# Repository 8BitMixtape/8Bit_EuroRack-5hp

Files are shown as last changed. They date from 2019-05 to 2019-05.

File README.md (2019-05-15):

# 8Bit_EuroRack-5hp

This was the first design and concept... 

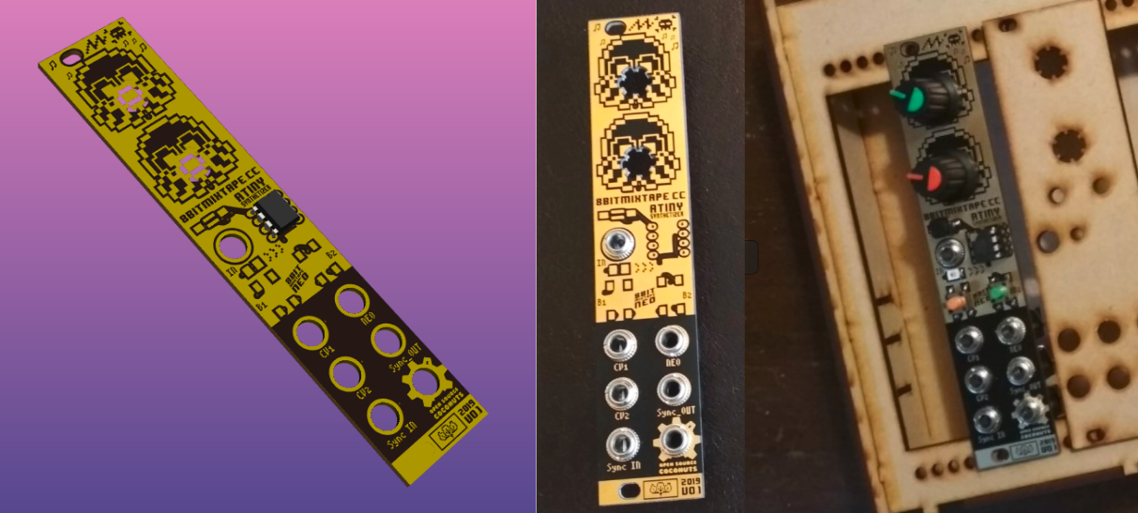
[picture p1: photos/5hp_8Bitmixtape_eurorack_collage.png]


* single PCB layer as frontplate AND circuit
* screw pots with solded pads on backside, like the 8Bit Mixtape NEO
* Vertical 3.5mm jacks, needs a bit of wiring to the PCB
* Attiny85 Chip on frontside. 8bit style

## Connections
* IN (for programming with audio)
* CV1 and CV2 IN - Connected to the input of potentiometers
* Sync IN - same connection as buttons. read as High to check for Sync signal (still needs to be coded)
* Sync OUT - from reset pin aka PB5 - change fuse settings to disable reset and solder little jumperpads on PCB
* NEO OUT - from PB0 to control NEO-Pixels or use as any other I/O pin.
* Coconut - That's the Main sound output aka PB0 with little RC filter

## Interface design drafts

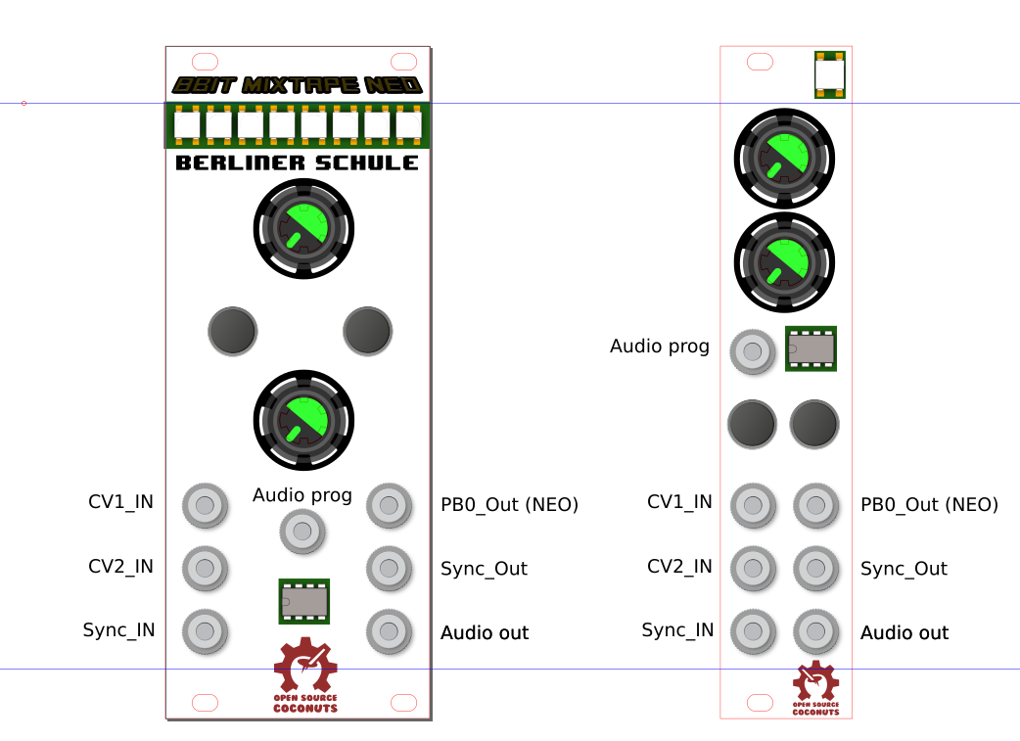
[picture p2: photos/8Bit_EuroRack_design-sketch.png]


## KiCAD PCB and 3d View

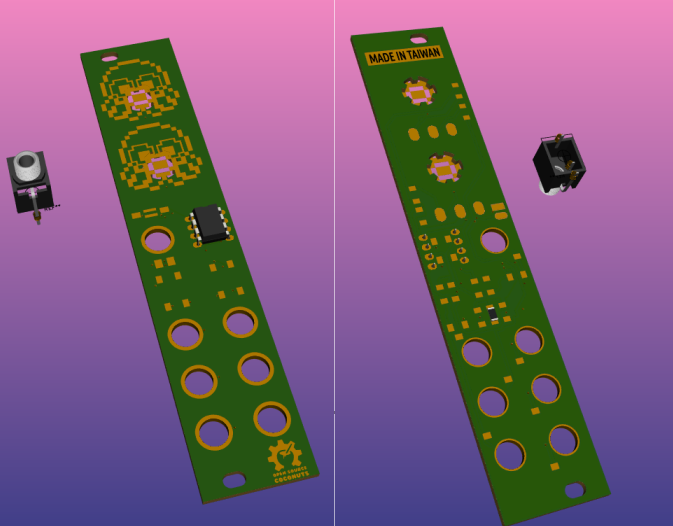
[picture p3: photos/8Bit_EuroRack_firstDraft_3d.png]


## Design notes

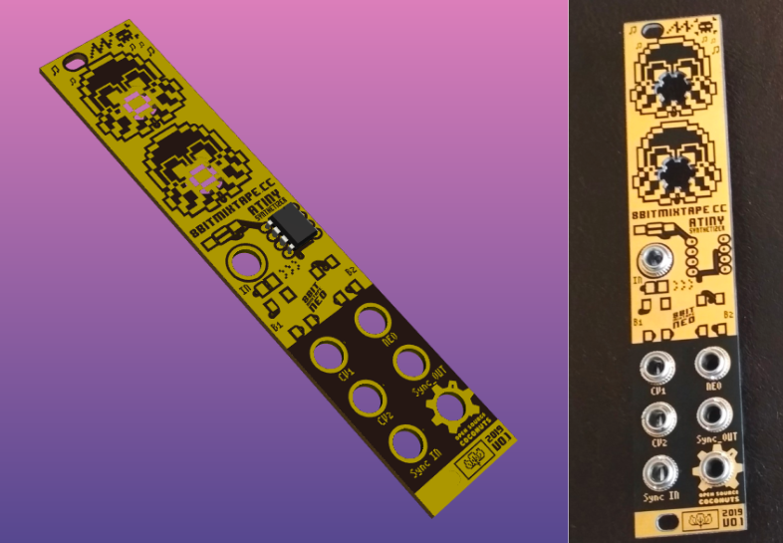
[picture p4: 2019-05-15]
photos/5hp_8Bitmixtape_eurorack.png

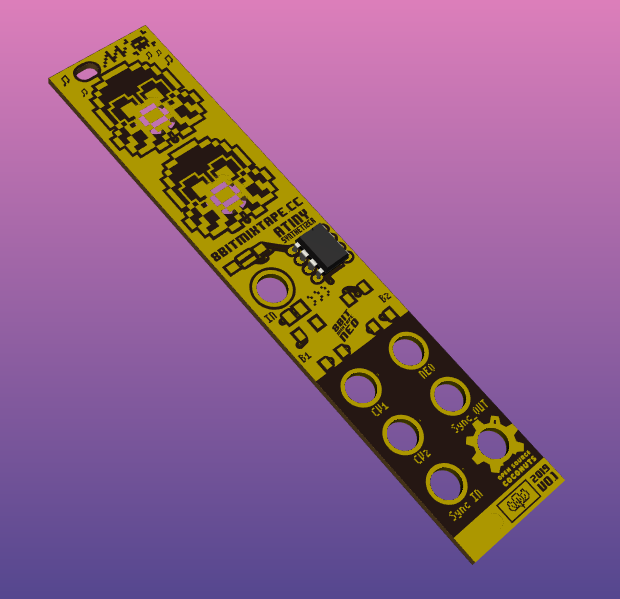
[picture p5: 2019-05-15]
photos/8Bit_EuroRack_v01_3d.png

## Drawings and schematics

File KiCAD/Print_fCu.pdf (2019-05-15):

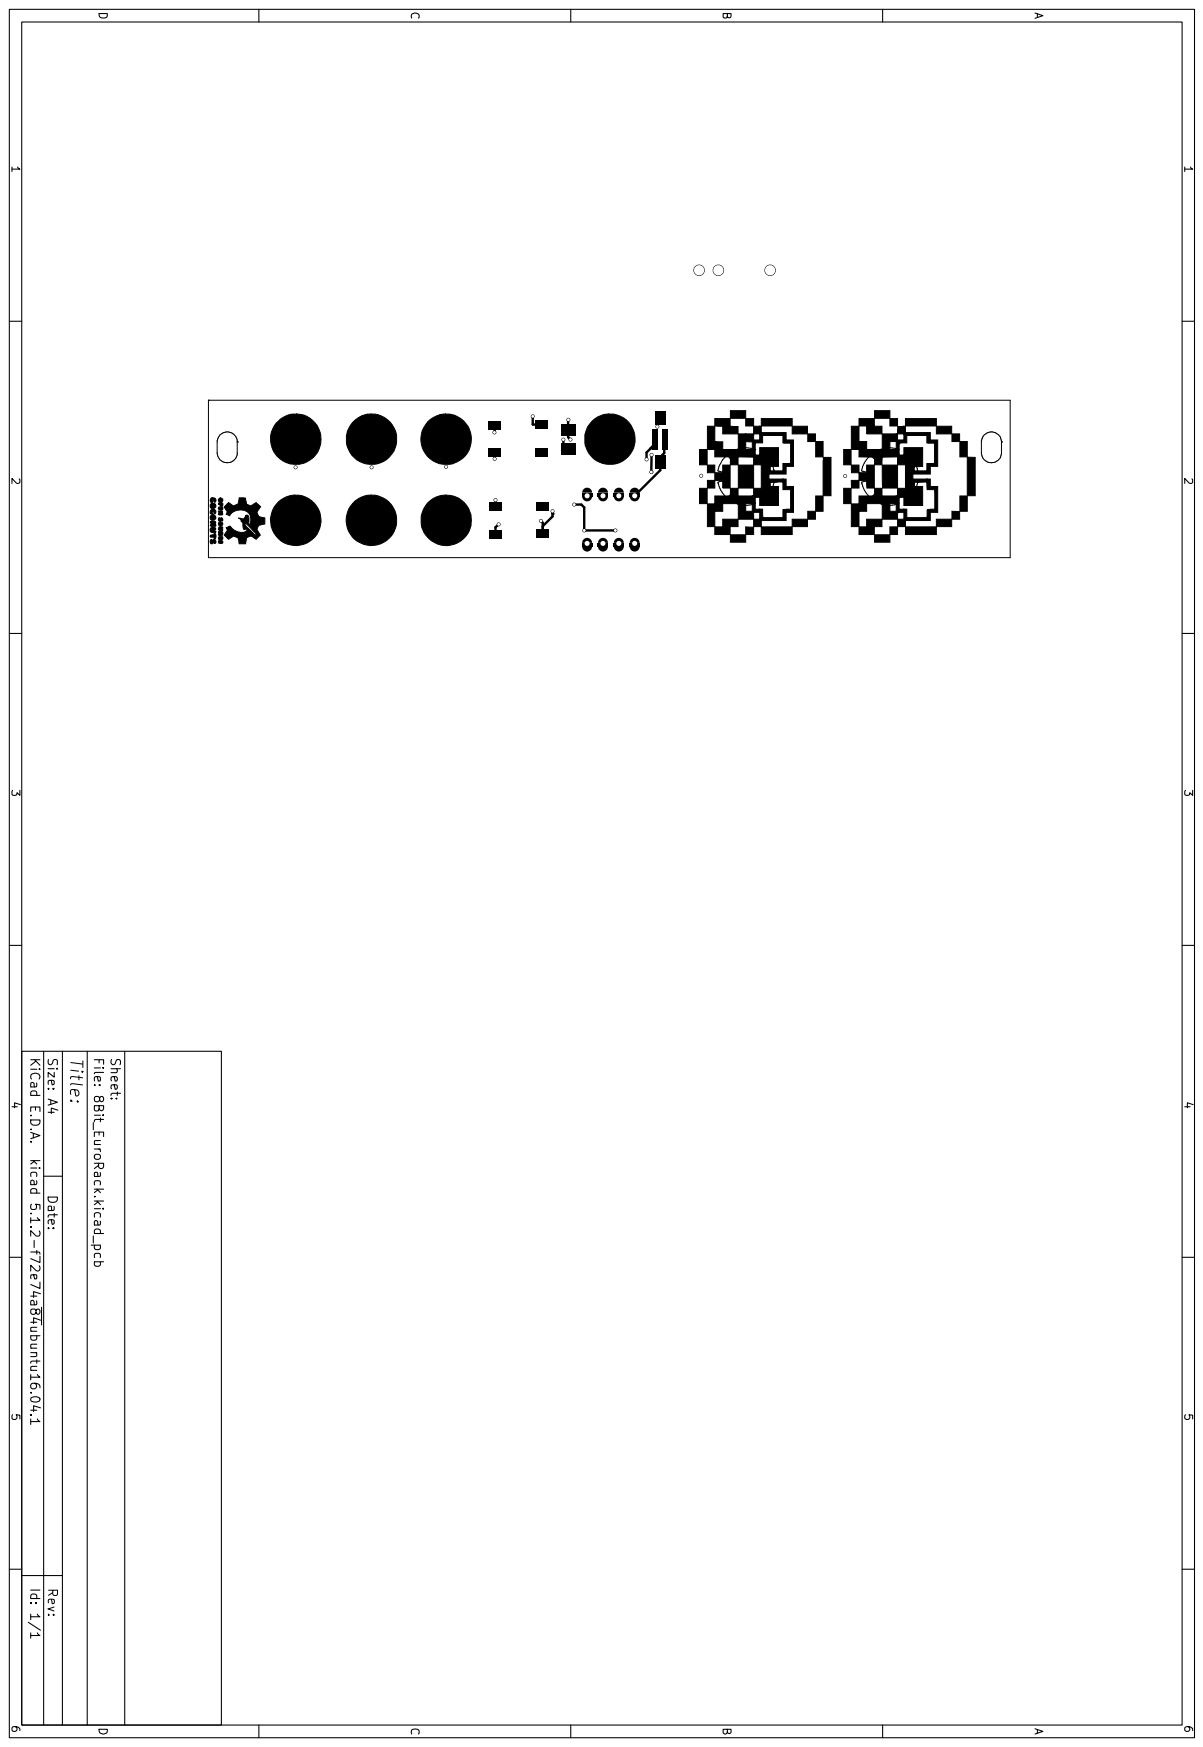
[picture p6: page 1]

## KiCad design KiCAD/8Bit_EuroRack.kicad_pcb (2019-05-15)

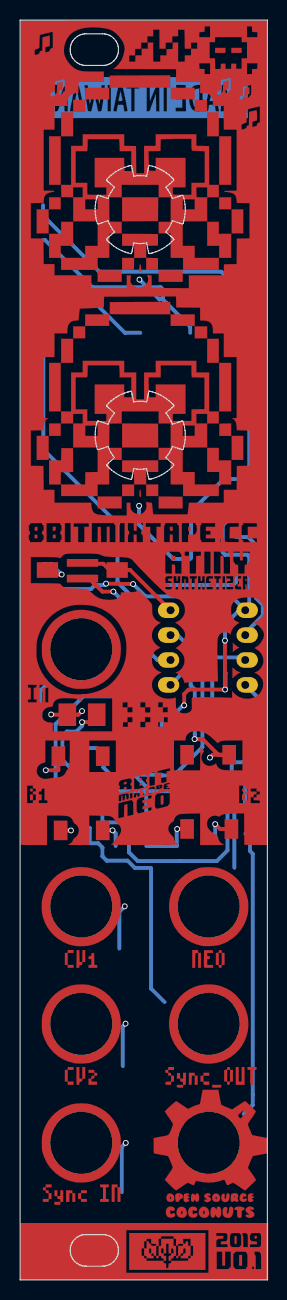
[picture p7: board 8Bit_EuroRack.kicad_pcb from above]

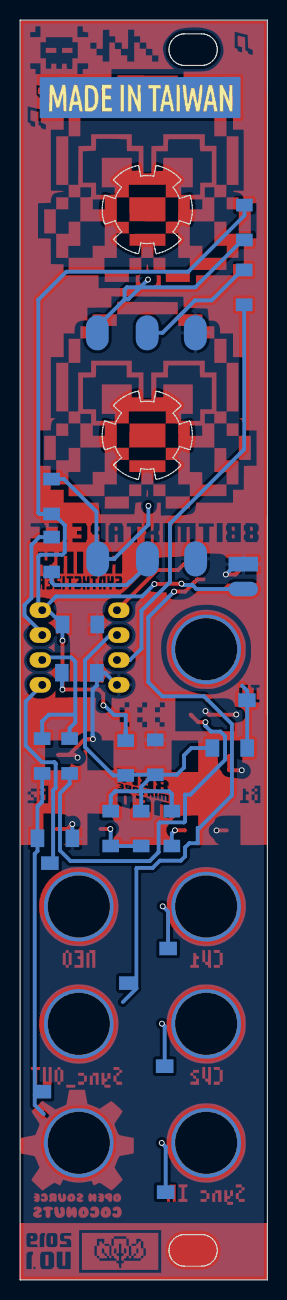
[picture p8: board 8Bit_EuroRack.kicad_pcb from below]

Board: 2 copper layers, 25.2 x 128.5 mm, 25 parts (16 on the bottom side), 15 nets.

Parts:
C1, C2, C3: 100nF; C_1206_HandSoldering
C4: 10uF; C_1206_HandSoldering
D-OUT1: LED; LED_2835_minimal
J4: Con_3-5V; Bat_connector_SMD
J6: Sync_Jumper; Sync_jumper
POT1-MAIN1, POT2-CV1: POT 10K lin; Potentiometer_backPads_noHole
R1, R2, R3, R4, R5: 22k; R_1206_HandSoldering
R6, R7: 22K; R_1206_HandSoldering
R8: 330; R_1206_HandSoldering
R10, R11: 4.7K; R_1206_HandSoldering
R13: 1K; R_1206_HandSoldering
Ref**: Val**; 8Bit_EuroRack-NEO_mini_frontplate
SW2, SW3: SW_Push; TACTILE-PTH_6mm_SMD
SW4: SW_Push; SW_SPST_FSMSM
U1: ATTINY85-20SU; Attiny_DIP-8_W7.62mm_mod

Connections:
+3V3: C2.1, C4.1, J4.2, R1.1, R10.1, R11.1, U1.8
But-L: R3.2, SW2.1
But-R: R4.2, R5.2, SW3.1
CV1_IN: POT2-CV1.1, R10.2
CV2_IN: POT1-MAIN1.1, R11.2
CV_OUT: C3.1, R8.1
GND: C2.2, C3.2, C4.2, D-OUT1.1, J4.1, POT1-MAIN1.3, POT2-CV1.3, R2.2, SW2.2, SW3.2, SW4.2, U1.4
unnamed: D-OUT1.2, R13.2
unnamed: J6.1, SW4.1, U1.1
unnamed: POT1-MAIN1.2, R7.2
unnamed: POT2-CV1.2, R6.2
PB1: R8.2, R13.1, U1.6
PB2/A1: R7.1, U1.7
PB4/A2: R6.1, U1.3
Sync_IN: C1.2, R1.2, R2.1, R3.1, R4.1, R5.1, U1.2

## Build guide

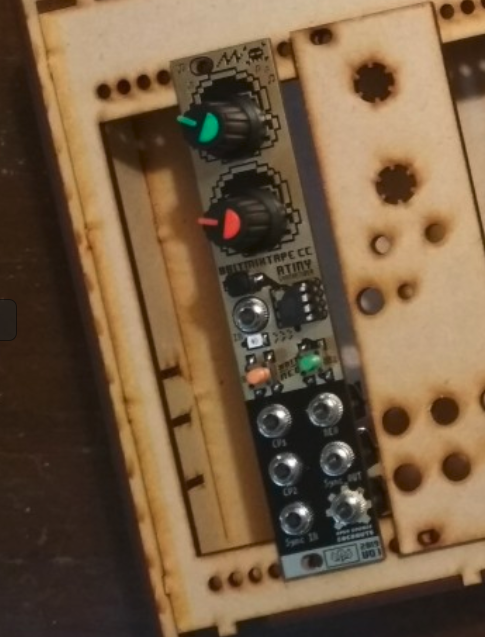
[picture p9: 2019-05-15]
photos/5hp_8Bitmixtape_eurorack_soldered.png

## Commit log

2019-05-06 clean files
    [8Bit_EuroRack-2019-05-06-11-40-01.sch, 8Bit_EuroRack.kicad_pcb, 8Bit_EuroRack.sch]
2019-05-06 adding screenshots
    [8Bit_EuroRack.kicad_pcb]
2019-05-15 adding photos
    [8Bit_EuroRack-B_Cu.gbr, 8Bit_EuroRack-B_Mask.gbr, 8Bit_EuroRack-B_SilkS.gbr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]
